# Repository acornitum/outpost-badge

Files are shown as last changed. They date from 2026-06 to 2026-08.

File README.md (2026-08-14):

# Outpost badges!



These are e-ink badges that I made for Outpost! They're built with the RP2354 and have an onboard e-ink driver - I also did the art on it :D

Includes:
- 2.9in e-ink screen
- NFC capabilities
- 6 tactile buttons that snap right onto the board
- 15 additional gpio pins broken out to use with the perfboard at the bottom
- USB-C for power and programming
- 3 lanyard holes that fit single + double clip lanyards, and badge clips
- 4 mounting holes in case you want to 3d print a case 

[Here](https://user-cdn.hackclub-assets.com/019ff91c-0464-7b39-83fa-bce072a783c1/img_1220__yafw_balanced_.mp4) is a video of flappy bird on it! Firmware by [@SamDev-7](https://github.com/SamDev-7)

img_1220__yafw_balanced_

You can also use it to play doom (the badge is only used as a monitor + input in this gif) :D

badgedoomgif

---

### PCB + schematic:




---

HUGE thanks to [@cyao](https://github.com/cheyao) for helping with the design, and ordering the boards! The badge would not have worked without the countless reviews and feedback. 

Additional thanks to [@mpkendall](https://github.com/mpkendall) and [@KaiPereira](https://github.com/KaiPereira) for reviewing the board!

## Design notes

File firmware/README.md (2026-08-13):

# Outpost badge firmware

**Status: work in progress. This is capability-testing firmware, not a product.**

The purpose of this code is to find out what the board can actually do and to
prove that a given board works: the RP2354A, the USB stack, the SSD1680 e-paper
panel, and the buttons. Everything here exists to answer a question or to
demonstrate a capability. Nothing here is a finished application.

Written in collaboration with Claude.

A note on the numbers here. Timings come from the board's own serial output, so
frame rates and refresh times are real measurements. Contrast is not: every
"good", "worse" or "too faint" in this folder is a judgement by eye, made from
A/B runs at matched frame rates. No optical instrument was used.

## What is proven

| Item | Status |
|---|---|
| RP2354A, USB, internal flash, CircuitPython | works |
| SSD1680 panel, full refresh | works, 2.29 s |
| SSD1680 partial refresh | works, 0.617 s stock |
| Fast partial refresh, 9.4 fps | works — see [epaper/README.md](epaper/README.md) |
| Animation demos (gradient, ball) | work |
| Playable game at ~9 fps | works |
| Buttons | works — all six, switch-to-ground (pull-up, active low) |
| NFC (ST25DV04K) and the LED behind it | not tried |
| Behaviour at low temperature | not tried |
| Long-term panel safety of the short waveform | argued, not measured |

## Board facts

- **MCU:** RP2354A — an RP2350 with 2 MB of stacked internal flash. There is no
  external flash IC. It programs over the normal BOOTSEL USB bootloader.
- **Panel:** `0290BN800F6HP-DL`, 2.9 inch, 296x128, SSD1680 controller.
- **CircuitPython:** the stock `raspberry_pi_pico2` build works unchanged. The
  RP2 port reads the flash size from the chip's JEDEC ID, so CIRCUITPY sizes
  itself to the internal 2 MB.

### Pin map

| Signal | GPIO | Note |
|---|---|---|
| E-paper CS | GP13 | |
| E-paper SCK | GP14 | SPI1 SCK |
| E-paper MOSI | GP15 | SPI1 TX |
| E-paper BUSY | GP16 | high means busy |
| E-paper D/C | GP17 | |
| E-paper RST | GP18 | active low |
| Button up | GP7 | |
| Button left | GP8 | |
| Button right | GP6 | |
| Button down | GP9 | |
| Button A | GP5 | |
| Button B | GP4 | |
| NFC ST25DV04K | GP10, GP11 | I2C |
| NFC GPO | GP12 | |

The buttons are wired switch-to-ground: enable an internal pull-up and read a
press as a low level. Confirmed on hardware by playing `epaper/examples/flappy.py`.

The LED (D4) is driven by the NFC chip, not by a GPIO, so it cannot be used as a
"hello world" blink.

### Orientation

Landscape with the FPC cable to the **left**. The native row axis (296) runs
horizontally and the column axis (128) runs vertically. A vertical run on screen
is a contiguous bit run inside one panel row, which is the cheap drawing
primitive. See [epaper/README.md](epaper/README.md) for the full geometry notes.

## Layout

Work is split by subsystem. Each subsystem owns its own document, examples and
experiment trail. `lib/` and `tools/` are shared, because subsystems will
eventually be used together and a driver buried inside one of them is awkward to
import from the other. Only `epaper/` exists so far; NFC would be added as a
sibling.

```
firmware/
  lib/                 drivers; deployed to CIRCUITPY/lib/
    ssd1680.py         e-paper
  tools/               shared
    deploy.sh          copy lib/ + one script to a mounted CIRCUITPY
    monitor.py         read the serial console
  epaper/
    README.md          how the fast refresh works, and what it costs
    examples/          things that work, and that show a capability
    experiments/       the trail that produced the numbers
    tools/             recondition.py, compare.py  (panel-specific)
```

### lib/

- `ssd1680.py` — raw SSD1680 driver: full refresh, stock partial refresh, and
  the fast partial path (custom LUT, charge pump held up, old-RAM sync).

### epaper/examples/

- `gradient.py` — scrolling dithered gradient
  ([video](https://cdn.hackclub.com/019ff91d-8611-714b-98ba-4ad0f98be064/img_1216__yafw_balanced_.mp4)).
  This is the reference setting: 9.4 fps, confirmed good contrast. Use it to
  check a board end to end.
- `ball.py` — bouncing ball with free-fall physics
  ([video](https://cdn.hackclub.com/019ff91c-ea26-7483-82a6-17ceeb6396bf/img_1219__yafw_balanced_.mp4)).
  Solid black, which is a harder case for a short waveform than a dithered grey.
- `flappy.py` — Flappy Bird at ~8.9 fps
  ([video](https://cdn.hackclub.com/019ff91c-0464-7b39-83fa-bce072a783c1/img_1220__yafw_balanced_.mp4)).
  Buttons flap; set `AUTO_PILOT = True` for the computer player.

### tools/ (shared)

- `deploy.sh` — copy `lib/` and one script onto a mounted CIRCUITPY.
- `monitor.py` — read the board's serial console.

### epaper/tools/

- `recondition.py` — **ghost remover.** Run it when the panel shows residual
  images. It restores the factory waveform and drives 8 full black-white
  inversions. One white refresh does not clear deep ghosting.
- `compare.py` — A/B contrast harness. Runs two settings at the same frame rate
  with letter cards between them, so contrast can be judged by eye without the
  frame rate confusing the comparison.

## Quick start

```bash
./firmware/tools/deploy.sh gradient
```

Then watch the console:

```bash
python3 firmware/tools/monitor.py /dev/cu.usbmodem101 20 passive
```

The argument to `deploy.sh` is a bare name or a path under `firmware/`:

```bash
./firmware/tools/deploy.sh flappy
./firmware/tools/deploy.sh epaper/examples/ball.py
./firmware/tools/deploy.sh recondition
```

`lib/*.py` goes to `CIRCUITPY/lib/`, and the chosen script becomes
`CIRCUITPY/code.py`. CircuitPython re-runs `code.py` on every save, so copying a
file restarts the program. Pass `passive` to `monitor.py` to avoid sending
Ctrl-C and Ctrl-D on top of that auto-restart.

## Three rules that are not optional

The first two are explained with measurements in
[epaper/README.md](epaper/README.md). All three are also documented at the top of
`lib/ssd1680.py`, next to the code they apply to.

1. **Keep the old RAM in sync during partial refresh.** Use
   `frame_nopower(..., sync_old=True)`. Without it, charge accumulates in one
   direction and the panel stops responding after about 80 frames, with no sign
   of trouble in the timing data.
2. **Call `epd.init()` before any full refresh that follows `arm_partial()`.**
   `arm_partial()` leaves the custom waveform loaded, so a plain full refresh
   runs the short waveform and is almost invisible: 0.613 s instead of 2.29 s.
3. **Call `epd.power_off()` when you finish, from a `finally`.**
   `arm_partial()` leaves the charge pump up on purpose — that is where the
   free speed comes from — and only `power_off()` lowers it. A full refresh
   powers down inside its own sequence; the fast path does not.

   `except KeyboardInterrupt` is not enough. CircuitPython's auto-reload fires
   every time `deploy.sh` copies a file, and it does not raise
   `KeyboardInterrupt`; neither does an unexpected exception. Both skip an
   except-only handler and leave the supply energised.

   ```python
   try:
       epd.arm_partial(tpa=2, frame_rate=0x44, groups=None)
       while True:
           epd.frame_nopower(buf, sync_old=True)
   finally:
       epd.power_off()
   ```

## If the panel looks wrong

- **Ghosting or faint leftover images** — run `./firmware/tools/deploy.sh
  recondition`.
- **A weak or invisible full refresh** — a missing `epd.init()`; see rule 2.
- **Motion stops after a few seconds** — a missing old-RAM sync; see rule 1.
- **Everything mirrored** — `FLIP_X` / `FLIP_Y` in `epaper/examples/flappy.py`. Note
  that a coordinate flip and the viewing inversion cancel for a static shape, so
  text does **not** need extra mirroring on top of `FLIP_X`.

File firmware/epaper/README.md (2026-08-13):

# Fast refresh on the SSD1680 e-paper panel

How this badge gets 9.4 frames per second out of a 2.9" e-paper panel, what it
costs, and which of the obvious ideas do not work.

All timings here are measured on this board: RP2354A, CircuitPython 10.2.1,
panel `0290BN800F6HP-DL` (296x128, SSD1680), SPI at 20 MHz, room temperature.
They come from the board's own serial output.

Contrast is a different matter. Every contrast rating below — "good", "slightly
worse", "no visible image" — is a judgement by eye, made from A/B runs at
matched frame rates. No optical instrument was used. The ratings are repeatable
and they were the basis for the settings chosen, but they are not measurements.

## Reference points

| Update type | Time for each frame | Speed |
|---|---|---|
| Factory full refresh | 2.29 s | 0.44 fps |
| Factory partial refresh | 0.617 s | 1.6 fps |
| Partial refresh, charge pump held up | 0.478 s | 2.1 fps |
| **This firmware** | **0.107 s** | **9.4 fps** |

That is 21 times faster than a full refresh and 5.8 times faster than the stock
partial refresh.

## Why e-paper looks slow

The 2.29 s full refresh is not a limit of the pigment. It is a choice in the
waveform. The factory waveform drives every pixel black and white several times
before it sets the final colour. That clears the previous image and it balances
the electric charge on each pixel.

The factory partial refresh already skips those clearing passes and drives only
the pixels that change. That alone is the 2.29 s to 0.617 s step, and it is why
partial refresh exists.

What remains in that 0.617 s is approximately 438 ms of real pigment drive. The
factory picked that number so the image is correct at low temperature, on a weak
unit from the production line, after any previous image, with margin on top. It
cannot know your conditions. You can measure yours.

## The three changes

### 1. Hold the charge pump up (free)

The controller has an internal charge pump that makes the high drive voltages.
It needs approximately 139 ms to raise and lower. A normal driver treats each
update as a complete transaction, so it pays that cost on every frame:

    power up -> load waveform -> send frame -> update -> power down

`arm_partial()` does the setup one time. `frame_nopower()` then runs only the
per-frame part:

    send frame -> update -> copy frame into the old RAM

Result: 0.617 s to 0.478 s. This change touches no voltage and no waveform, so
contrast is unaffected. It is the only large gain that costs nothing.

Cost: the analog supply stays on between frames, so current draw is continuous.
We did not measure it. The code must call `power_off()` when it stops.

### 2. Shorten the waveform (costs contrast)

The custom LUT replaces the factory table. Two fields control the drive time:

    drive time of group 0 = tpa x frame period

- `tpa` is the number of frames in group 0, the phase group that draws.
- The frame-rate byte sets the length of one frame from the controller's
  oscillator.

Groups 1 and 2 are hold phases. They cost 20 ms and they draw nothing, but they
are not free in image terms — see the measurements below.

Result: 0.478 s to 0.107 s. This is where every millisecond of contrast goes.

### 3. Copy each frame into the old RAM (required)

The controller picks each pixel's waveform by comparing the old RAM (`0x26`)
against the new RAM (`0x24`). A pixel whose two values match selects a `VSS`
entry and gets no drive at all.

If the old RAM is left holding an old frame, the controller drives the same
pixels the same direction on every frame. Charge builds one way. **The image
looks good for approximately 80 frames and then all motion stops at once.**

That failure is not visible in timing data. The broken version held a steady
18.4 fps, with normal BUSY times and no timeouts, while the panel stopped
responding. It looked like the power had been cut.

`frame_nopower(..., sync_old=True)` does the copy. It costs approximately 3 ms,
or 5 percent of the frame rate (18.4 fps to 17.4 fps). It is not optional.

The panel recovered completely from this after `recondition.py`, so the damage
observed was not permanent. Do not rely on that.

## Measurements

### Speed against contrast

**These numbers describe one panel, in one set of conditions.** They come from a
single unit at room temperature, judged by eye by one person under their own
lighting. Panel-to-panel variation, temperature, viewing angle and ambient light
all move the point where contrast stops being acceptable. A colder panel needs
more drive for the same result.

Treat the table as a starting point, not as a specification. On another board,
re-run `tools/compare.py`, which runs two settings at matched frame rates so
contrast can be compared without frame rate confusing the judgement, and pick
your own point on the curve. The *shape* of the trade should hold — contrast
follows total panel time — but the acceptable threshold is yours to find.

Every row uses `sync_old=True` and mode `0x04`.

| tpa | Frame rate | Groups | Drive | Panel | Total | Speed | Contrast |
|---|---|---|---|---|---|---|---|
| 2 | 0x44 | 3 | 40 ms | 99.8 ms | 106.9 ms | 9.4 fps | good — the milestone |
| 3 | 0x44 | 1 | 60 ms | 99.8 ms | 106.9 ms | 9.4 fps | the same as above |
| 1 | 0x44 | 3 | 20 ms | 79.8 ms | 87.0 ms | 11.5 fps | slightly worse |
| 2 | 0x44 | 1 | 40 ms | 79.8 ms | 87.0 ms | 11.5 fps | slightly worse |
| 1 | 0x44 | 1 | 20 ms | 59.8 ms | 67.1 ms | 14.9 fps | worse |
| 1 | 0x88 | 1 | 10 ms | 49.8 ms | 57.0 ms | 17.5 fps | no visible image |
| 1 | 0xFF | 1 | 10 ms | 50.4 ms | 57.6 ms | 17.4 fps | no visible image |

Two results follow from this table:

1. **Contrast follows the total panel time.** The split between hold phases and
   drive does not matter. Rows 1 and 2 run at the same speed with the time spent
   in different places, and they look the same. Rows 3 and 4 do the same at
   11.5 fps.
2. **There is no free speed left.** Every step below 99.8 ms costs contrast.

At the bottom row the animation still runs. The pigment simply does not move far
enough to see: the panel shows faint moving lines and no image.

### The fixed cost

Approximately 39.8 ms of every frame is fixed. It does not change with the
waveform, the line count, or anything else we found. That sets a ceiling near
25 fps, and no image survives at that end.

Frame period at 0x44 is 20 ms. The frame-rate byte stops helping at 0x88; 0xFF
gives no more speed.

### Things that do not work

| Idea | Result |
|---|---|
| Drive fewer gate lines (a window) | **nothing.** 296 lines 0.05048 s, 32 lines 0.05109 s |
| Reuse the loaded LUT (`0x22=0xC7`) | **nothing** |
| Frame-timing registers `0x3A` / `0x3B` | **nothing**, with either LUT |
| Waveshare `WF_PARTIAL` as published | 0.726 s — *slower*; the per-frame LUT reload costs more than it saves |

The window result is the important one, and it is not an oversight. The waveform
runs as a series of LUT frames whose length comes from the controller's
oscillator. That length does not depend on the gate-line count, so fewer lines
means the scan finishes early and then waits.

**A game cannot save time by updating a small region on this panel.** Plan for a
whole-screen redraw every frame.

## Two defects worth not repeating

### A full refresh after `arm_partial()` is weak

`arm_partial()` writes the custom LUT into `0x32` and overwrites the voltage
registers `0x03`, `0x04` and `0x2C`. Nothing puts the factory table back. Every
later `display_full()` therefore runs the short partial waveform.

Measured: 0.613 s instead of 2.29 s, and almost invisible on the panel.

`epd.init()` does a software reset, which restores the factory table from OTP.
Call it before any full refresh that follows partial-refresh use:

```python
epd.init()
epd.display_full(buf)
```

### Seeding with real content burns it in

`display_base()` is a 2.29 s factory refresh, so whatever it shows is driven at
full strength and leaves the strongest ghost on the panel. Seed it with a blank
background, not with the first frame of content, and let the first partial
update draw the scene.

## The CPU is not the bottleneck

For the animation demos, all frames are built once at start and the loop only
sends bytes:

| Part | Time | Share |
|---|---|---|
| Panel BUSY | 99.7 ms | 93% |
| SPI + Python | 7.2 ms | 7% |

A perfect rewrite in C would give at most 6 percent. The panel owns the frame.

Live drawing does matter, but the fix is to remove repeated work, not to change
language. The first version of `flappy.py` cost 21.4 ms of CPU and ran at
7.8 fps. Two changes brought it to 4.9 ms and 8.9 fps:

- The ground line was redrawn across all 296 rows every frame. It is static, so
  it is now baked into a background buffer that the frame is copied from.
- Every row of a pipe is identical and its gap never changes while it scrolls,
  so the pipe's 16-byte row is built once when it spawns and then assigned.

Both changes stop repeating work. Neither is something C would have fixed.

## Reading the panel geometry

Landscape with the FPC cable to the **left**: the native row axis (296) runs
horizontally and the column axis (128) runs vertically.

- A vertical run on screen is a contiguous bit run inside one panel row. That is
  the cheap drawing primitive.
- A horizontal run on screen touches one bit in many rows. That is the expensive
  one.
- The viewer's left-to-right runs *backwards* along the panel rows on this
  board, which is what `FLIP_X` in `flappy.py` corrects. Note that a coordinate
  flip plus that viewing inversion cancel for a static shape, so text does
  **not** need mirroring on top of `FLIP_X`.

## What this gives up

Against the factory partial refresh, this firmware loses three things:

- **Contrast.** 40 ms of drive instead of 438 ms.
- **Temperature compensation.** The factory table is selected by the controller
  for the measured temperature. The custom table is fixed, so a cold panel will
  look weaker. Untested.
- **A clean state on exit.** The custom table stays loaded until `init()`.

Ghosting also builds up, because the clearing passes are skipped. Run
`recondition.py` when it shows.

One caution on safety. In group 0 the two directions use opposite voltages, so
shortening the drive should scale both equally and keep the per-pixel charge
balanced. That is an argument from the waveform table, not a measurement. We
have no instrument reading that confirms DC balance.

## Dithering

The panel has one bit for each pixel. A 4x4 Bayer pattern gives 17 grey levels.
Grey needs less pigment movement than solid black, so a short waveform suits a
dithered gradient much better than it suits text or solid shapes. A setting that
looks good on a gradient can look weak on a solid black object.

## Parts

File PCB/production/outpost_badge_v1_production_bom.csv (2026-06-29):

Designator | Footprint | Quantity | Value | LCSC Part #
BOOT1 | SW_Push_1P1T_XKB_TS-1187A | 1 | BOOT | C318884
C1, C2 | Capacitor 0402 | 2 | 4.7u | C7472957
C10, C11, C13, C14, C15, C16, C17, C18, C19, C4, C6 | 0402 | 11 | 100n | C60474
C12, C9 | 0805 | 2 | 10u | C5137471
C20, C21 | 0603 | 2 | 4.7uF | C7419427
C22 | 0402 | 1 | 0.1uF | C60474
C23 | 0402 | 1 | 33pF | C5137486
C24, C25, C26, C27, C28, C29, C30, C31, C32, C33 | 0402 | 10 | 1uF | C5359886
C3, C5 | 0402 | 2 | 4.7u | C7472957
C7, C8 | 0402 | 2 | 15p | C325460
D1, D2, D3 | D_SOD-123 | 3 | MBR0530 | C82046
D4 | 0805 | 1 | LED | C2297
J1 | USB_C_Receptacle_GCT_USB4105-xx-A_16P_TopMnt_Horizontal | 1 | USB_C_Receptacle_USB2.0_14P | C2765186
J2 | PinHeader_1x03_P2.54mm_Vertical | 1 | Conn_01x03
J3 | PinHeader_1x14_P2.54mm_Vertical | 1 | Conn_01x14_Pin
J4 | PinHeader_1x16_P2.54mm_Vertical | 1 | Conn_01x16_Pin
J5, J6 | PinHeader_1x03_P2.54mm_Vertical | 2 | Conn_01x03_Pin
L1 | Abracon AOTA-B201610S3R3-101-T | 1 | 3.3u | C42411119
L2 | L_APV_ANR4018 | 1 | 47uH 500mA | C167808
L3 | KiCadAntenna | 1 | NFC antenna
Q1 | SOT-323_SC-70 | 1 | Si1308EDL | C7603347
R1, R2 | 0402 | 2 | 5.1k | C2906874
R10 | 0402 | 1 | 1M | C93949
R11, R14, R9 | 0402 | 3 | 10k | C190095
R12 | 0402 | 1 | 2.2R | C327251
R13 | 0402 | 1 | 47 | C854484
R3 | 0402 | 1 | 33 | C453643
R4, R5, R6 | 0402 | 3 | 1k | C852624
R7, R8 | 0402 | 2 | 27 | C2909343
RESET1 | SW_Push_1P1T_XKB_TS-1187A | 1 | RESET | C318884
SW1, SW2, SW3, SW4, SW5, SW6 | SW_PUSH-12mm_Wuerth-430476085716 | 6 | SW_Push
U1 | SOT-23-6 | 1 | SRV05-4 | C151305
U2 | QFN-60-1EP_7x7mm_P0.4mm_EP3.4x3.4mm_ThermalVias | 1 | RP2350_60QFN | C41378174
U3 | SOT-223-3_TabPin2 | 1 | NCP1117-3.3_SOT223 | C20546
U4 | ST_UFDFPN-12-1EP_3x3mm_P0.5mm_EP1.4x2.55mm | 1 | ST25DV04K-JFR6D3 | C2654815
U5 | Jushuo_AFC07-S24FCA-00_1x24-1MP_P0.50_Horizontal | 1 | Conn | C262643
Y1 | Crystal_SMD_3225-4Pin_3.2x2.5mm | 1 | ABM8-272-T3 | C20625731

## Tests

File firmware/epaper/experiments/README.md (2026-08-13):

# Experiments

The trail that produced the numbers in [../README.md](../README.md).
None of these is needed to use the firmware. They are kept because each one is
the evidence behind a claim, and because re-running one is the fastest way to
check a claim that later looks wrong.

Each file changes **one** variable from the file above it. That was deliberate:
several earlier conclusions were wrong because two things changed at once.

| File | One change from | What it showed |
|---|---|---|
| `replay_accum.py` | the original demo | Baseline, looping. Motion stops after ~80 frames (4–5 s), abruptly, while the firmware keeps running at 18.4 fps. The "freeze" in the original was only the script ending. |
| `power_probe.py` | `replay_accum` | Re-asserting analog power every 60 frames. **No effect** — it is not the charge pump. |
| `sync_probe.py` | `replay_accum` | `sync_old` False → True. Motion never stops again, at a cost of 5% speed. This is the fix. It also revealed that the image was invisible at that drive time. |
| `drive_probe.py` | `sync_probe` | tpa 1 → 2, frame rate 0xFF → 0x44. 9.4 fps with a clearly visible wave. |
| `shape_probe.py` → `../examples/gradient.py` | `drive_probe` | Folded triangle → one sine period. Single peak. This became the milestone. |
| `groups_probe.py` | `shape_probe` | Groups 3 → 1 at the same drive. 11.5 fps, contrast slightly worse. The hold phases are **not** free. |
| `fps_probe.py` | `shape_probe` | tpa 2 → 1. 11.5 fps. |
| `fps_probe2.py` | `fps_probe` | Groups 3 → 1. 14.9 fps. |
| `fps_probe3.py` | `fps_probe2` | Frame rate 0x44 → 0x88. 17.5 fps, and 0xFF gives no more — the byte saturates. |
| `wave10.py` | `shape_probe` | Hold phases traded for drive: 1 group + 60 ms. Same 9.4 fps, and it looks the same as 3 groups + 40 ms. Contrast follows total panel time, not how the time is split. |
| `wave.py`, `code.py` | — | Earlier versions, superseded. `code.py` is the windowing test with the gate-line count set before power-up. |
| `validate.py` | — | Staged visual check (baseline, checkerboard, motion, ghost). Written before the sync fix; its conclusions predate it. |
| `ladder.py` | — | Drive-time ladder, ~400 ms down to ~10 ms. Written but never run; `compare.py` replaced it. |

## Re-running one

```bash
./firmware/tools/deploy.sh epaper/experiments/sync_probe.py
python3 firmware/tools/monitor.py /dev/cu.usbmodem101 25 passive
```

## What went wrong, and why the one-variable rule exists

Three conclusions in this folder's history were wrong, and each had the same
cause — more than one thing changed between observations.

1. **"Windowing, LUT reuse and frame timing are all dead ends."** True in the
   end, but first measured while a 139 ms charge-pump cycle was being paid on
   every frame and swamping everything else.
2. **"The freeze was charge accumulation."** The original demo was a fixed
   120-frame run that finished and exited. It never failed at all.
3. **"Mode 2 (`0x22=0x0C`) is required for partial refresh."** The fix was the
   old-RAM sync, which was changed at the same time. The working firmware uses
   mode `0x04`.

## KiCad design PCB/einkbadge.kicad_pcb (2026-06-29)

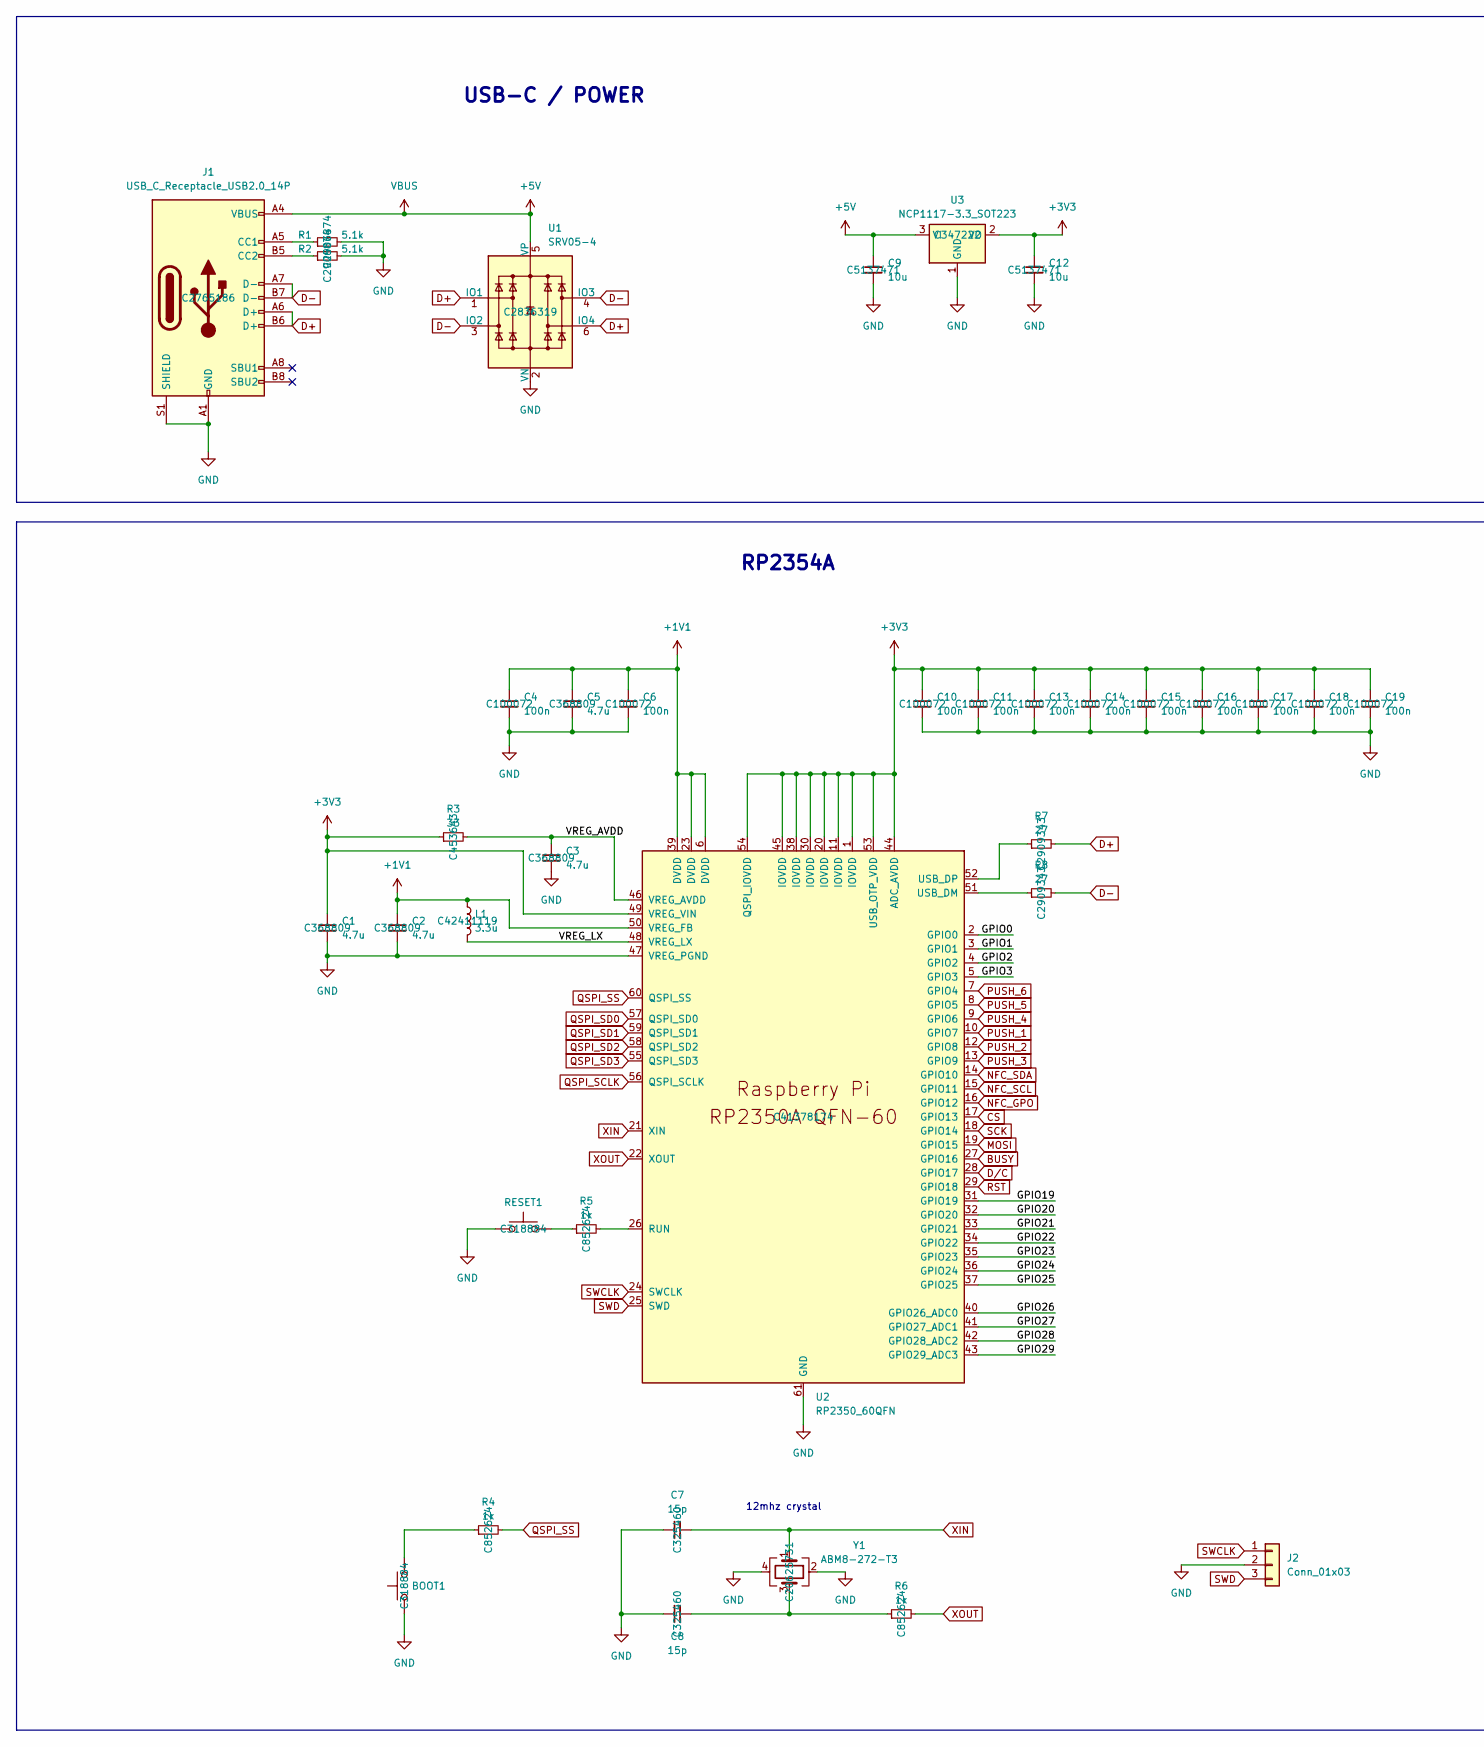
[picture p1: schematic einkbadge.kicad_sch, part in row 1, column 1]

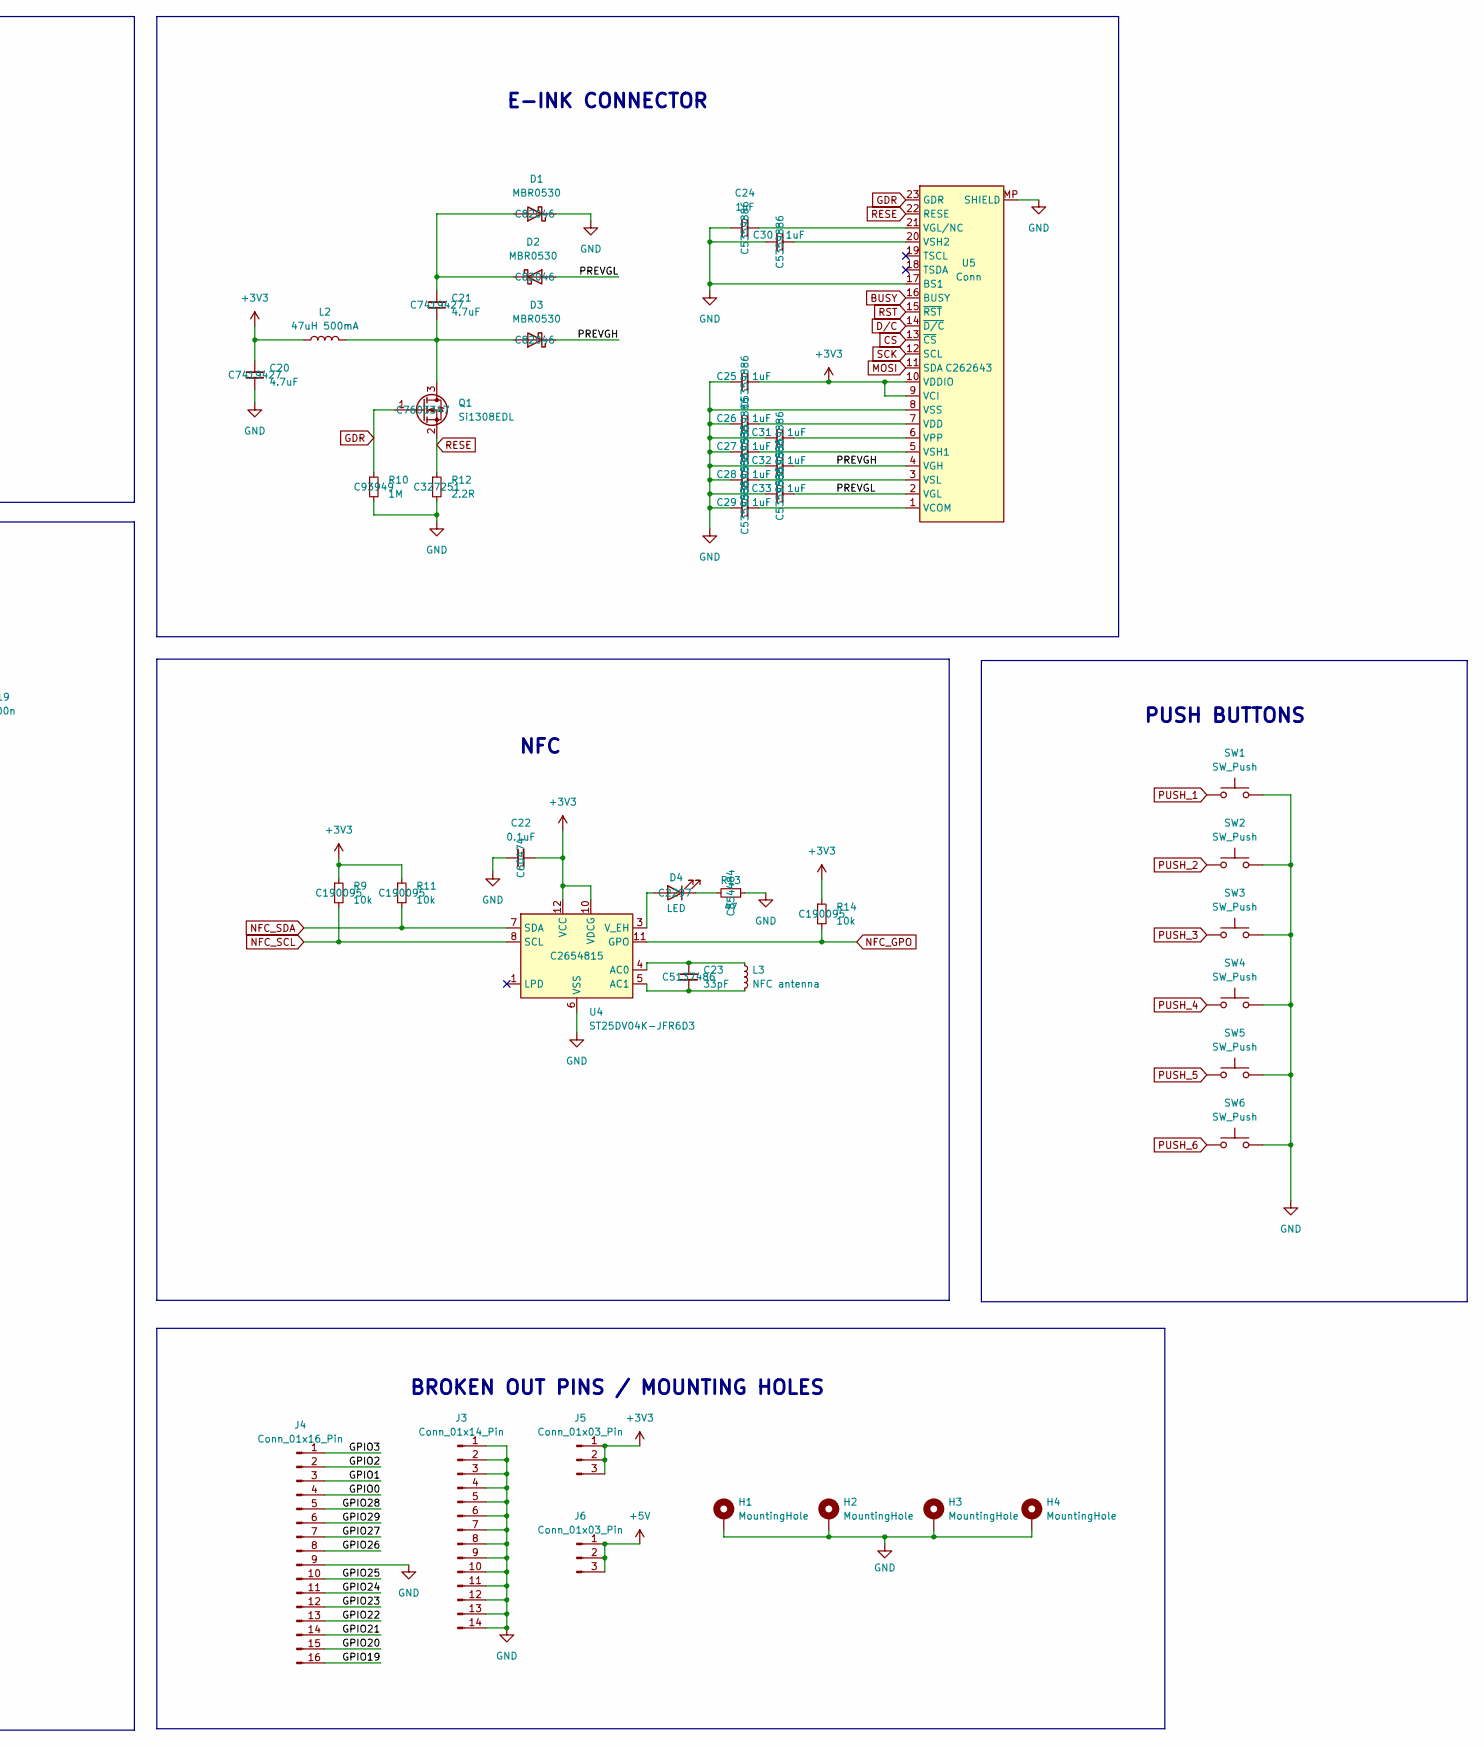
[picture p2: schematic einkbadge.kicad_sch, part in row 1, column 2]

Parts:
BOOT1: BOOT; SW_Push_1P1T_XKB_TS-1187A; LCSC Part # C318884
C1, C2: 4.7u; Capacitor 0402; LCSC Part # C368809
C3, C5: 4.7u; C_0402_1005Metric; LCSC Part # C368809
C4, C6, C10, C11, C13, C14, C15, C16, C17, C18, C19: 100n; C_0402_1005Metric; LCSC Part # C100072
C7, C8: 15p; C_0402_1005Metric; LCSC Part # C325460
C9, C12: 10u; C_0805_2012Metric; LCSC Part # C5137471
C20, C21: 4.7uF; C_0603_1608Metric; LCSC Part # C7419427
C22: 0.1uF; C_0402_1005Metric; LCSC Part # C60474
C23: 33pF; C_0402_1005Metric; LCSC Part # C5137486
C24, C25, C26, C27, C28, C29, C30, C31, C32, C33: 1uF; C_0402_1005Metric; LCSC Part # C5359886
D1, D2, D3: MBR0530; D_SOD-123; LCSC Part # C82046
D4: LED; LED_0805_2012Metric; LCSC Part # C2297
H1, H2, H3, H4: MountingHole; MountingHole_2.2mm_M2_Pad_Via
J1: USB_C_Receptacle_USB2.0_14P; USB_C_Receptacle_GCT_USB4105-xx-A_16P_TopMnt_Horizontal; LCSC Part # C2765186
J2: Conn_01x03; PinHeader_1x03_P2.54mm_Vertical
J3: Conn_01x14_Pin; PinHeader_1x14_P2.54mm_Vertical
J4: Conn_01x16_Pin; PinHeader_1x16_P2.54mm_Vertical
J5, J6: Conn_01x03_Pin; PinHeader_1x03_P2.54mm_Vertical
L1: 3.3u; Abracon AOTA-B201610S3R3-101-T; LCSC Part # C42411119
L2: 47uH 500mA; L_APV_ANR4018; LCSC Part # C167808
L3: NFC antenna; KiCadAntenna
Q1: Si1308EDL; SOT-323_SC-70; LCSC Part # C7603347
R1, R2: 5.1k; R_0402_1005Metric; LCSC Part # C2906874
R3: 33; R_0402_1005Metric; LCSC Part # C453643
R4, R5, R6: 1k; R_0402_1005Metric; LCSC Part # C852624
R7, R8: 27; R_0402_1005Metric; LCSC Part # C2909343
R9, R11, R14: 10k; R_0402_1005Metric; LCSC Part # C190095
R10: 1M; R_0402_1005Metric; LCSC Part # C93949
R12: 2.2R; R_0402_1005Metric; LCSC Part # C327251
R13: 47; R_0402_1005Metric; LCSC Part # C854484
RESET1: RESET; SW_Push_1P1T_XKB_TS-1187A; LCSC Part # C318884
SW1, SW2, SW3, SW4, SW5, SW6: SW_Push; SW_PUSH-12mm_Wuerth-430476085716
U1: SRV05-4; SOT-23-6; LCSC Part # C2836319
U2: RP2350_60QFN; QFN-60-1EP_7x7mm_P0.4mm_EP3.4x3.4mm_ThermalVias; LCSC Part # C41378174
U3: NCP1117-3.3_SOT223; SOT-223-3_TabPin2; LCSC Part # C347222
U4: ST25DV04K-JFR6D3; ST_UFDFPN-12-1EP_3x3mm_P0.5mm_EP1.4x2.55mm; LCSC Part # C2654815
U5: Conn; Jushuo_AFC07-S24FCA-00_1x24-1MP_P0.50_Horizontal; LCSC Part # C262643
Y1: ABM8-272-T3; Crystal_SMD_3225-4Pin_3.2x2.5mm; LCSC Part # C20625731

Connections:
+1V1: C2.1, C4.1, C5.1, C6.1, L1.1, U2.6 (DVDD), U2.23 (DVDD), U2.39 (DVDD), U2.50 (VREG_FB)
+3V3: C1.1, C10.1, C11.1, C12.1, C13.1, C14.1, C15.1, C16.1, C17.1, C18.1, C19.1, C20.1, C22.2, C25.2, J5.1, J5.2, J5.3, L2.1, R3.1, R9.1, R11.1, R14.1, U2.1 (IOVDD), U2.11 (IOVDD), U2.20 (IOVDD), U2.30 (IOVDD), U2.38 (IOVDD), U2.44 (ADC_AVDD), U2.45 (IOVDD), U2.49 (VREG_VIN), U2.53 (USB_OTP_VDD), U2.54 (QSPI_IOVDD), U3.2 (VO), U4.10 (VDCG), U4.12 (VCC), U5.9 (VCI), U5.10 (VDDIO)
+5V: C9.1, J1.A4 (VBUS), J1.A9 (VBUS), J1.B4 (VBUS), J1.B9 (VBUS), J6.1, J6.2, J6.3, U1.5 (VP), U3.3 (VI)
/GPIO0: J4.4, U2.2 (GPIO0)
/GPIO1: J4.3, U2.3 (GPIO1)
/GPIO2: J4.2, U2.4 (GPIO2)
/GPIO3: J4.1, U2.5 (GPIO3)
/GPIO19: J4.16, U2.31 (GPIO19)
/GPIO20: J4.15, U2.32 (GPIO20)
/GPIO21: J4.14, U2.33 (GPIO21)
/GPIO22: J4.13, U2.34 (GPIO22)
/GPIO23: J4.12, U2.35 (GPIO23)
/GPIO24: J4.11, U2.36 (GPIO24)
/GPIO25: J4.10, U2.37 (GPIO25)
/GPIO26: J4.8, U2.40 (GPIO26_ADC0)
/GPIO27: J4.7, U2.41 (GPIO27_ADC1)
/GPIO28: J4.5, U2.42 (GPIO28_ADC2)
/GPIO29: J4.6, U2.43 (GPIO29_ADC3)
/PREVGH: C32.2, D3.1 (K), U5.4 (VGH)
/PREVGL: C33.2, D2.2 (A), U5.2 (VGL)
/VREG_AVDD: C3.1, R3.2, U2.46 (VREG_AVDD)
/VREG_LX: L1.2, U2.48 (VREG_LX)
BUSY: U2.27 (GPIO16), U5.16 (BUSY)
CS: U2.17 (GPIO13), U5.13 (~CS)
D+: J1.A6 (D+), J1.B6 (D+), R7.2, U1.1 (IO1), U1.6 (IO4)
D-: J1.A7 (D-), J1.B7 (D-), R8.2, U1.3 (IO2), U1.4 (IO3)
D/C: U2.28 (GPIO17), U5.14 (~D/C)
GDR: Q1.1 (G), R10.1, U5.23 (GDR)
GND: BOOT1.1, C1.2, C2.2, C3.2, C4.2, C5.2, C6.2, C7.1, C8.1, C9.2, C10.2, C11.2, C12.2, C13.2, C14.2, C15.2, C16.2, C17.2, C18.2, C19.2, C20.2, C22.1, C24.1, C25.1, C26.1, C27.1, C28.1, C29.1, C30.1, C31.1, C32.1, C33.1, D1.1 (K), H1.1 (1_1), H2.1 (1_1), H3.1 (1_1), H4.1 (1_1), J1.A1 (GND), J1.A12 (GND), J1.B1 (GND), J1.B12 (GND), J1.S1 (SHIELD), J2.2, J3.1, J3.2, J3.3, J3.4, J3.5, J3.6, J3.7, J3.8, J3.9, J3.10, J3.11, J3.12, J3.13, J3.14, J4.9, R1.2, R2.2, R10.2, R12.2, R13.1, RESET1.1, SW1.2, SW2.2, SW3.2, SW4.2, SW5.2, SW6.2, U1.2 (VN), U2.47 (VREG_PGND), U2.61 (GND), U3.1 (GND), U4.6 (VSS), U5.8 (VSS), U5.17 (BS1), U5.MP (SHIELD), Y1.2, Y1.4
MOSI: U2.19 (GPIO15), U5.11 (SDA)
NFC_GPO: R14.2, U2.16 (GPIO12), U4.11 (GPO)
NFC_SCL: R9.2, U2.15 (GPIO11), U4.8 (SCL)
NFC_SDA: R11.2, U2.14 (GPIO10), U4.7 (SDA)
unnamed: BOOT1.2, R4.1
unnamed: C8.2, R6.1, Y1.3
unnamed: C21.2, D1.2 (A), D2.1 (K)
unnamed: C21.1, D3.2 (A), L2.2, Q1.3 (D)
unnamed: D4.2 (A), U4.3 (V_EH)
unnamed: D4.1 (K), R13.2
unnamed: J1.A5 (CC1), R1.1
unnamed: J1.B5 (CC2), R2.1
unnamed: R5.1, RESET1.2
unnamed: R5.2, U2.26 (RUN)
unnamed: R8.1, U2.51 (USB_DM)
unnamed: R7.1, U2.52 (USB_DP)
unnamed: C23.1, L3.1, U4.4 (AC0)
unnamed: C23.2, L3.2, U4.5 (AC1)
unnamed: C29.2, U5.1 (VCOM)
unnamed: C26.2, U5.7 (VDD)
unnamed: C24.2, U5.21 (VGL/NC)
unnamed: C31.2, U5.6 (VPP)
unnamed: C27.2, U5.5 (VSH1)
unnamed: C30.2, U5.20 (VSH2)
unnamed: C28.2, U5.3 (VSL)
PUSH_1: SW1.1, U2.10 (GPIO7)
PUSH_2: SW2.1, U2.12 (GPIO8)
PUSH_3: SW3.1, U2.13 (GPIO9)
PUSH_4: SW4.1, U2.9 (GPIO6)
PUSH_5: SW5.1, U2.8 (GPIO5)
PUSH_6: SW6.1, U2.7 (GPIO4)
QSPI_SCLK: U2.56 (QSPI_SCLK)
QSPI_SD0: U2.57 (QSPI_SD0)
QSPI_SD1: U2.59 (QSPI_SD1)
QSPI_SD2: U2.58 (QSPI_SD2)
QSPI_SD3: U2.55 (QSPI_SD3)
QSPI_SS: R4.2, U2.60 (QSPI_SS)
RESE: Q1.2 (S), R12.1, U5.22 (RESE)
RST: U2.29 (GPIO18), U5.15 (~RST)
SCK: U2.18 (GPIO14), U5.12 (SCL)
SWCLK: J2.1, U2.24 (SWCLK)
SWD: J2.3, U2.25 (SWD)
XIN: C7.2, U2.21 (XIN), Y1.1
XOUT: R6.2, U2.22 (XOUT)

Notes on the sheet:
USB-C / POWER
RP2354A
PUSH BUTTONS
NFC
12mhz crystal
E-INK CONNECTOR
BROKEN OUT PINS / MOUNTING HOLES

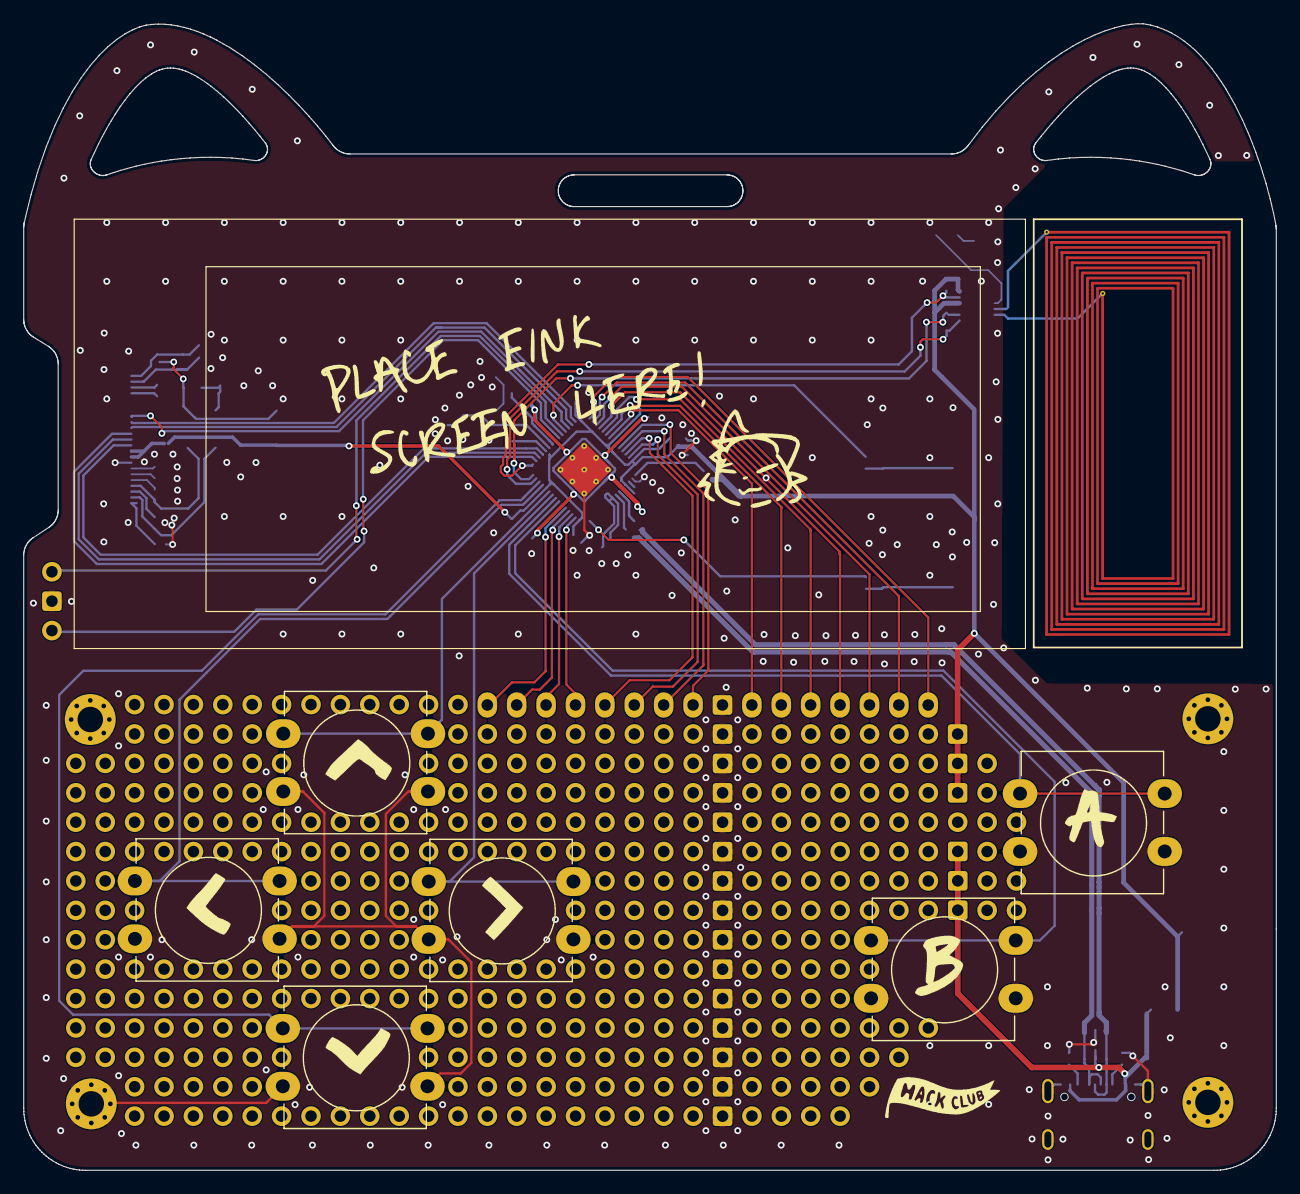
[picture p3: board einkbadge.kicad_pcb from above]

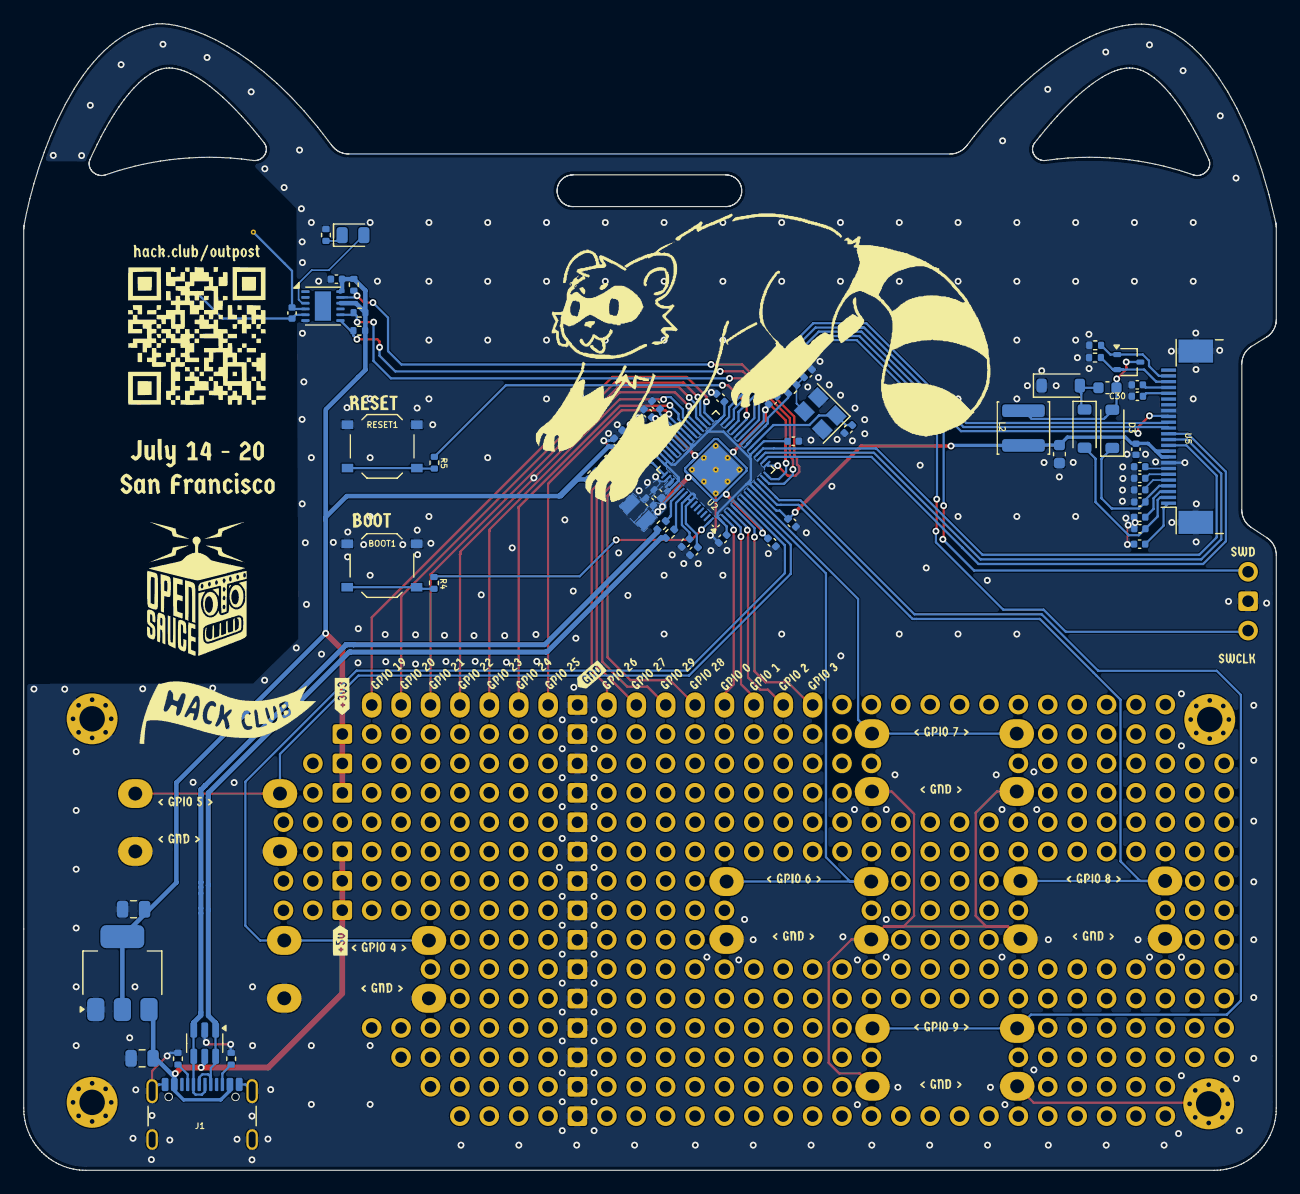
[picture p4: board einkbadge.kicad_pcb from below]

Board: 2 copper layers, 108.2 x 99.1 mm, 79 parts (64 on the bottom side), 68 nets.

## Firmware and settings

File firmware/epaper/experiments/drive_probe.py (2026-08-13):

# drive_probe.py -- sync_probe + exactly one change: more drive time.
#
# Exactly ONE variable is changed from the run that was confirmed to look good:
# the frame count. Everything else is byte-for-byte the original -- same 16
# precomputed frames, same folded-triangle ramp along the ROW axis (so the
# double peaks are back; that is intentional, this is the known-good baseline),
# same 20 MHz SPI, same DISPLAY Mode 1 (0x04), same *absent* old-RAM sync.
#
# The original did not fail. It was a fixed 120-frame run that finished:
#     --> maximum (tpa=1 fr=0xFF groups=1)
#         18.4 fps end-to-end (54.3 ms/frame)
#     done -- clean full refresh.
#     Code done running.
# It "froze" because it ran out of frames and exited, not because of the panel.
#
# What we are testing here: does that same picture hold up past 120 frames, and
# if it degrades, how does it degrade and when? Do NOT add a fix to this file.
# If it walks toward black, that is the result -- record it, then change one
# variable in a separate file and compare against this.
#
# Ctrl-C is the stop. It powers down and leaves a clean full refresh.

import time
import board
import busio
from ssd1680 import SSD1680, WIDTH, HEIGHT

STRIDE = WIDTH // 8          # 16 bytes/row
NROWS = HEIGHT               # 296
NFRAMES = 16                 # animation frames held in RAM (~74 KB)
REPORT_EVERY = NFRAMES       # report once per wave cycle, so a cycle number on
                             # the console can be matched to what the panel is
                             # doing. Logging only -- the display path is
                             # untouched.

# (label, tpa, frame_rate, groups, frames);  frames = 0 -> loop forever
SETTINGS = (
    ("balanced", 2, 0x44, None, 0),
)

spi = busio.SPI(clock=board.GP14, MOSI=board.GP15)
epd = SSD1680(spi, board.GP13, board.GP17, board.GP18, board.GP16, baudrate=20_000_000)
epd.timeout = 3.0

print("\n=== FULL-SCREEN gradient PoC (baseline, looping) ===")
print("init ok:", epd.init())

# ---- 4x4 Bayer dither -> per (level, row%4) 16-byte row patterns -----------
BAYER = ((0, 8, 2, 10), (12, 4, 14, 6), (3, 11, 1, 9), (15, 7, 13, 5))

print("building dither patterns...")
ROWPAT = []                                  # ROWPAT[level][row % 4] -> bytes
for level in range(17):
    per_phase = []
    for r4 in range(4):
        row = bytearray(STRIDE)
        for bx in range(STRIDE):
            byte = 0
            for bit in range(8):
                col = bx * 8 + bit
                # black where the dither threshold is under the level
                if BAYER[r4][col & 3] >= level:
                    byte |= 0x80 >> bit      # 1 = white
            row[bx] = byte
        per_phase.append(bytes(row))
    ROWPAT.append(per_phase)

# ---- precompute the animation frames --------------------------------------
print("precomputing %d frames..." % NFRAMES)
t0 = time.monotonic()
FRAMES = []
for f in range(NFRAMES):
    phase = f * (NROWS // NFRAMES)
    buf = bytearray(STRIDE * NROWS)
    for row in range(NROWS):
        t = (row + phase) % NROWS
        lvl = t * 32 // NROWS                # triangle wave 0..16..0
        if lvl > 16:
            lvl = 32 - lvl
        off = row * STRIDE
        buf[off:off + STRIDE] = ROWPAT[lvl][row & 3]
    FRAMES.append(buf)
print("built in %.1fs (%d KB)" % (time.monotonic() - t0,
                                  NFRAMES * STRIDE * NROWS // 1024))

# ---- play it back ---------------------------------------------------------
try:
    for label, tpa, fr, groups, frames in SETTINGS:
        epd.display_base(FRAMES[0])
        epd.arm_partial(tpa=tpa, frame_rate=fr, groups=groups)
        print("\n--> %s (tpa=%d fr=0x%02X groups=%s)%s"
              % (label, tpa, fr, groups, "" if frames else "  [looping]"))
        i = 0
        shown = 0
        busy = 0.0
        t0 = time.monotonic()
        while frames == 0 or i < frames:
            # sync_old=False restores the original behaviour: the driver gained
            # a sync_old parameter after this run, defaulting to True.
            _, tb, _ = epd.frame_nopower(FRAMES[i % NFRAMES], mode=0x04,
                                         sync_old=True)
            busy += tb
            i += 1
            shown += 1
            if shown == REPORT_EVERY:
                dt = time.monotonic() - t0
                print("    cycle %3d | frame %5d | %.1f fps (%.1f ms/frame; panel %.1f, rest %.1f)"
                      % (i // NFRAMES, i, shown / dt, dt / shown * 1000,
                         busy / shown * 1000, (dt - busy) / shown * 1000))
                t0 = time.monotonic()
                shown = 0
                busy = 0.0
        epd.power_off()
        time.sleep(1.0)
    print("\ndone -- clean full refresh.")
    epd.display_full(FRAMES[0])
except KeyboardInterrupt:
    epd.power_off()
    print("\nstopped -- clean full refresh.")
    epd.display_full(FRAMES[0])

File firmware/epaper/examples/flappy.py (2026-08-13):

# flappy.py -- automated Flappy Bird on the e-paper panel.
#
# Display settings are the confirmed milestone (shape_probe.py): tpa=2, frame
# rate 0x44, 3 groups, sync_old=True, mode 0x04. Measured 9.4 fps, panel
# 99.8 ms, 40 ms of drive. The game runs at that tick and the physics constants
# suit it, not 60 fps.
#
# No buttons are wired, so an auto-pilot plays. It aims the bird at the middle
# of the next gap and flaps whenever the bird is below it.
#
# LOOKAHEAD is 0 on purpose. A 3-frame prediction was the first attempt and it
# died at the first pipe in every game: "by + vy*3 > target" fires a flap while
# the bird is still ~12 px ABOVE the target, and each flap lifts it 12 px more,
# so the oscillation centre climbs until the bird clips the top of the gap.
# With no prediction the bird oscillates around the target instead of above it.
#
# GRAVITY, FLAP and LOOKAHEAD come from a host-side parameter sweep, not from
# guesswork. At these values: 20 games x 20000 frames, zero deaths, and the
# bird stays inside y = 23..105 of a 0..127 panel.
#
# Drawing cost matters here, unlike the pre-rendered demos. Only ~7 ms of each
# frame is not panel time, so live drawing eats frame rate directly. The first
# version cost 21.4 ms of CPU and dropped the game to 7.8 fps. Two things fixed
# it, and both remove repeated work rather than making the work faster:
#   * the ground line is baked into a background buffer, not redrawn on 296
#     rows every frame;
#   * every row of a pipe is identical and a pipe's gap never changes while it
#     scrolls, so its 16-byte row is built once at spawn and then assigned.
#
# Orientation: landscape, FPC cable LEFT. The native row axis (296) runs
# horizontally on screen and the column axis (128) runs vertically. Screen
# coordinates below are (x across, y down). If the bird falls UPWARDS set
# FLIP_Y = True; if the pipes travel the wrong way set FLIP_X = True.

import random
import time
import board
import busio
import digitalio
from ssd1680 import SSD1680, WIDTH, HEIGHT

STRIDE = WIDTH // 8
NROWS = HEIGHT               # 296 -> screen width  (x, horizontal)
NCOLS = WIDTH                # 128 -> screen height (y, vertical)

FLIP_X = True
FLIP_Y = False

# ---- buttons ---------------------------------------------------------------
# Six switches on the badge. Any of them flaps.
#   left pad : up GP7, left GP8, right GP6, down GP9
#   right pad: A GP5, B GP4
# Wiring is switch-to-ground: internal pull-up, and a press reads low. The
# schematic could not settle this on its own -- it uses plain SW_Push symbols,
# and an open switch just follows whichever pull is enabled, so the resting
# level is the same either way. Confirmed on hardware by playing the game.
BUTTON_PINS = (board.GP7, board.GP8, board.GP6, board.GP9, board.GP5, board.GP4)
PULL_UP = True
PRESSED_LEVEL = False        # pin level while a button is held down
DEBOUNCE = 0.02              # seconds; ignore edges closer together than this
AUTO_PILOT = False           # True restores the computer player

BUTTONS = []
for _p in BUTTON_PINS:
    _io = digitalio.DigitalInOut(_p)
    _io.direction = digitalio.Direction.INPUT
    _io.pull = digitalio.Pull.UP if PULL_UP else digitalio.Pull.DOWN
    BUTTONS.append(_io)

_held = False                # debounced "any button is down"
_edge_t = 0.0                # time of the last accepted edge
_latch = False               # a press happened and the game has not used it
_presses = 0


def poll():
    """Sample the buttons and latch a press.

    This runs from inside the driver's BUSY wait, which is the ~100 ms of each
    frame when the CPU is idle waiting for the panel. Sampling there costs no
    frame rate, and it catches a tap shorter than one frame -- reading the
    buttons only between frames would lose those.

    Debounce is by time: after an accepted edge, further edges are ignored for
    DEBOUNCE seconds, so contact chatter cannot register as several presses.
    """
    global _held, _edge_t, _latch, _presses
    now = time.monotonic()
    if now - _edge_t < DEBOUNCE:
        return
    down = False
    for b in BUTTONS:
        if b.value == PRESSED_LEVEL:
            down = True
            break
    if down != _held:
        _held = down
        _edge_t = now
        if down:                 # act on the press, not the release
            _latch = True
            _presses += 1


def take_press():
    """Consume a latched press. One tap gives exactly one flap, and holding a
    button down does not repeat."""
    global _latch
    if _latch:
        _latch = False
        return True
    return False

# ---- gameplay, tuned for a ~9 fps tick ------------------------------------
BIRD_X = 72
BIRD_R = 7
GRAVITY = 2.0
FLAP = -8.0
VMAX = 12.0
PIPE_W = 26
GAP = 48
PIPE_SPEED = 10
SPACING = 148                # x distance between pipes
MARGIN = 10                  # smallest distance from a gap to an edge
LOOKAHEAD = 0                # see the note above -- prediction made it worse
GROUND_Y = NCOLS - 1

spi = busio.SPI(clock=board.GP14, MOSI=board.GP15)
epd = SSD1680(spi, board.GP13, board.GP17, board.GP18, board.GP16, baudrate=20_000_000)
epd.timeout = 3.0

print("\n=== flappy bird ===")
print("init ok:", epd.init())


# ---- drawing ---------------------------------------------------------------
def span(buf, off, y0, y1):
    """Set screen rows y0..y1 of the panel row at byte offset `off` to black.
    A vertical run on screen is a contiguous bit run inside one panel row, so
    this is the cheap primitive. Bit 1 = white, so black means clearing bits."""
    if FLIP_Y:
        y0, y1 = NCOLS - 1 - y1, NCOLS - 1 - y0
    if y0 < 0:
        y0 = 0
    if y1 > NCOLS - 1:
        y1 = NCOLS - 1
    if y1 < y0:
        return
    b0 = y0 >> 3
    b1 = y1 >> 3
    if b0 == b1:
        m = 0
        for c in range(y0, y1 + 1):
            m |= 0x80 >> (c & 7)
        buf[off + b0] &= 0xFF ^ m
        return
    m = 0
    for c in range(y0, (b0 << 3) + 8):
        m |= 0x80 >> (c & 7)
    buf[off + b0] &= 0xFF ^ m
    for b in range(b0 + 1, b1):
        buf[off + b] = 0x00
    m = 0
    for c in range(b1 << 3, y1 + 1):
        m |= 0x80 >> (c & 7)
    buf[off + b1] &= 0xFF ^ m


def rect(buf, x0, x1, y0, y1):
    """Filled rectangle in screen coordinates."""
    if FLIP_X:
        x0, x1 = NROWS - 1 - x1, NROWS - 1 - x0
    if x0 < 0:
        x0 = 0
    if x1 > NROWS - 1:
        x1 = NROWS - 1
    for x in range(x0, x1 + 1):
        span(buf, x * STRIDE, y0, y1)


def disc(buf, cx, cy, r):
    for dx in range(-r, r + 1):
        h = int((r * r - dx * dx) ** 0.5)
        rect(buf, cx + dx, cx + dx, cy - h, cy + h)
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

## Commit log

2026-06-17 update schematic
    [einkbadge.kicad_pcb, einkbadge.kicad_sch]
2026-06-22 pcb routing almost done
    [einkbadge.kicad_pcb, einkbadge.kicad_sch]
2026-06-22 update pcb
    [einkbadge.kicad_pcb]
2026-06-22 fix pcb
    [einkbadge.kicad_pcb]
2026-06-23 pcb update (add gpio breakouts)
    [einkbadge.kicad_pcb, einkbadge.kicad_sch]
2026-06-26 add silkscreen, reroute eink connector
    also removed part label silkscreen
    [einkbadge.kicad_pcb]
2026-06-26 added lcsc part numbers
    [einkbadge.kicad_pcb, einkbadge.kicad_sch]
2026-06-26 add production files
    [einkbadge-B_Cu.gbl, einkbadge-B_Mask.gbs, einkbadge-B_Paste.gbp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]
2026-06-26 update 1uf lcsc part
    [einkbadge-B_Cu.gbl, einkbadge-B_Mask.gbs, einkbadge-B_Paste.gbp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]
2026-06-28 minor routing fix
    [einkbadge.kicad_pcb]
2026-06-29 Update silkscreen, soldermask and MPNs
    [einkbadge-B_Cu.gbl, einkbadge-B_Mask.gbs, einkbadge-B_Paste.gbp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]
2026-06-29 Fix bad git merge
    [einkbadge.kicad_pcb]
2026-08-13 Ignore scratch directory
    tmp/ holds CircuitPython UF2 downloads and vendor driver references used
    while working; none of it belongs in the repo.
2026-08-13 Add raw SSD1680 driver with fast partial refresh
    displayio.EPaperDisplay cannot do partial refresh, so the controller is
    driven with raw commands. Beyond a stock driver this splits the per-frame
    work from the setup:
    arm_partial() reset, load the waveform, bring the charge pump up
    frame_nopower() send a frame, update, sync the reference RAM
    Holding the charge pump up across frames takes a stock partial refresh
    from 0.617 s to 0.478 s and changes no voltage or waveform. Shortening
    the waveform (tpa, frame_rate, groups) takes it to 0.107 s and does cost
    contrast.
    Three rules are documented at the top of the file, all of which came from
    real failures:
    - sync_old=True is mandatory; wi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
2026-08-13 Add deploy and serial monitor tools
    deploy.sh copies lib/ to CIRCUITPY/lib/ and one named script to code.py,
    so experiments keep their own names in the repo instead of one file being
    overwritten in place. A bare name resolves against the subsystem folders.
    monitor.py reads the serial console. Its passive mode sends no Ctrl-C or
    Ctrl-D, which matters because CircuitPython's auto-reload already
    restarts code.py when deploy.sh copies it; sending a reboot on top of
    that starts the script twice.
    [monitor.py]
2026-08-13 Add e-paper examples and panel tools
    examples/
    gradient.py scrolling dithered gradient at 9.4 fps; the reference
    setting, and the quickest end-to-end check of a board
    ball.py bouncing ball, free-fall physics. Solid black, which is a
    harder case for a short waveform than a dithered grey
    flappy.py playable Flappy Bird at ~8.9 fps on the six buttons
    Flappy draws live rather than from pre-rendered frames, and drawing cost
    is visible at this frame rate: the first version spent 21.4 ms of CPU and
    ran at 7.8 fps. Baking the static ground into a background buffer and
    caching each pipe's row pattern brought it to 4.9 ms and 8.9 fps. Both
    changes remove re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
    [ball.py, compare.py, flappy.py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]
2026-08-13 Add the e-paper experiment trail
    Each file changes exactly one variable from the file above it. That was
    deliberate: three earlier conclusions were wrong because two things
    changed at once, including 'the freeze was charge accumulation' (the
    original demo was a fixed 120-frame run that simply ended) and 'Mode 2 is
    required for partial refresh' (the fix was the old-RAM sync, changed at
    the same time; the working firmware uses mode 0x04).
    None of this is needed to use the firmware. It is kept because each file
    is the evidence behind a number in epaper/README.md, and re-running one
    is the fastest way to check a claim that later looks wrong.
    [code.py, drive_probe.py, fps_probe.py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]
2026-08-13 Document the fast-refresh work
    firmware/README.md board facts, pin map, layout, quick start, and the
    three non-optional rules
    epaper/README.md how the fast refresh works and what it costs
    Both are explicit about evidence. Timings come from the board's serial
    output and are real measurements. Contrast is not: every 'good', 'worse'
    and 'too faint' is a judgement by eye from A/B runs at matched frame
    rates, on one panel, at room temperature, under one person's lighting.
    The speed/contrast table says so, because the threshold will move on
    another board.
    The DC-balance argument for why shortening the drive is safe is also
    flagged as reasoning from the waveform table r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
2026-08-13 clean up repo
    [einkbadge.kicad_pcb, einkbadge.kicad_sch, outpost_badge_v1_production_bom.csv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]
